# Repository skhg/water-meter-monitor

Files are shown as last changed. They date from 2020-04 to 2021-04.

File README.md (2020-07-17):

# water-meter-monitor
This is a project to measure my household water consumption in real-time using Arduino. The project also evolved a little bit to record the bathroom environment (temperature, humidity, etc).

This repo covers only the design and construction of the monitor. To record data, the [data logger](https://github.com/skhg/household-data-logger) project also needs to be run on the same LAN.

## The finished product
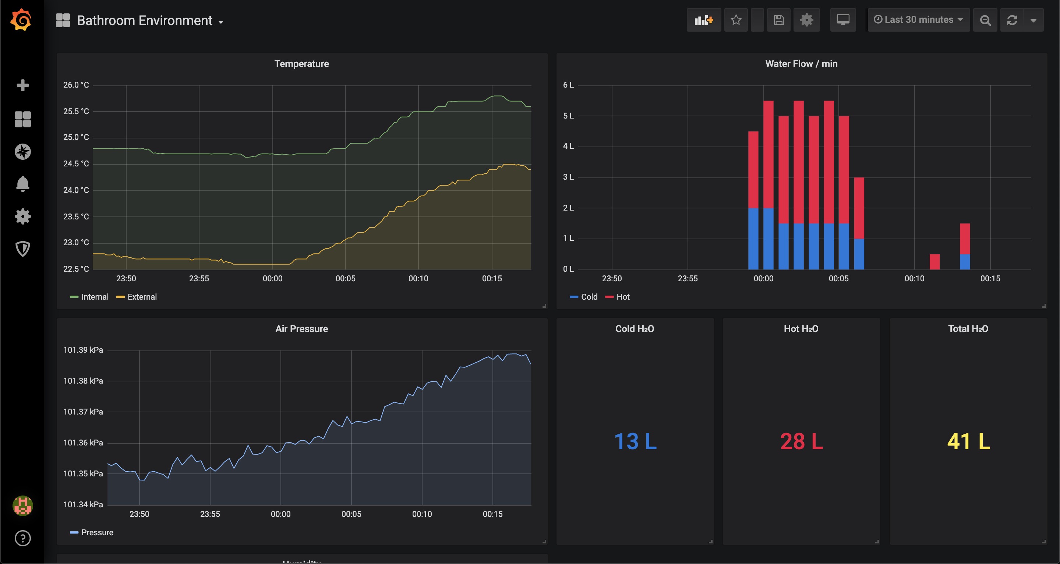
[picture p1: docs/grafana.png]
dashboard

A dashboard set up to display the data using [Grafana](https://grafana.com/). Again, see the [data logger](https://github.com/skhg/household-data-logger) project for how this is set up.

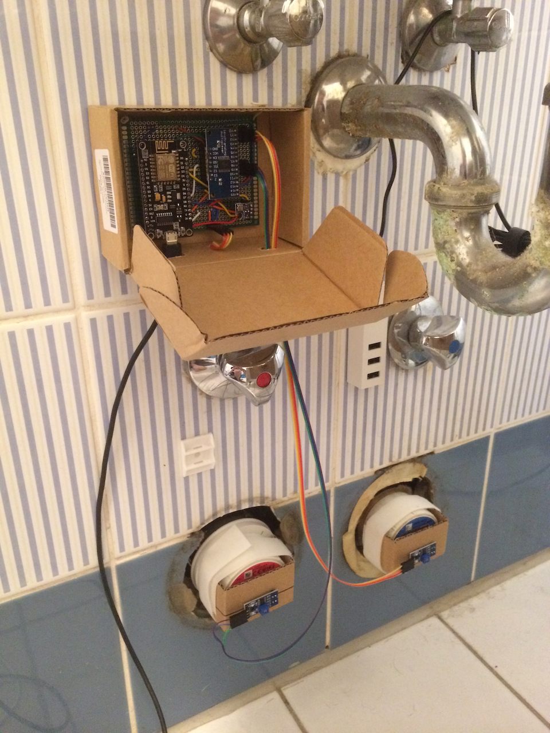
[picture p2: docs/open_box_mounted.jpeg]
installed hardware

The installed sensors and Arduino board. Please excuse the dirt and corroded pipes.

## Materials needed
* Hot/cold water meters with that spinning silver disc
* Arduino-compatible [NodeMCU ESP8266](https://www.amazon.de/dp/B06Y1ZPNMS/ref=pd_bap_rp_29?_encoding=UTF8&psc=1&refRID=00VJ4MZWJ40VXXT9V9F5) board.
* [BMP180 temperature/air pressure sensor](https://www.amazon.de/dp/B07D8S617X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)
* [DHT22 temperature/humidity sensor](https://www.amazon.de/dp/B06XF4TNT9/ref=pd_bap_rp_33?_encoding=UTF8&psc=1&refRID=00VJ4MZWJ40VXXT9V9F5)
* 2x [TCRT5000 Infrared reflectivity sensor](https://www.amazon.de/dp/B017CWS47E/ref=pd_bap_rp_35?_encoding=UTF8&psc=1&refRID=00VJ4MZWJ40VXXT9V9F5)
* [Multiplexer board](https://www.amazon.de/dp/B06Y1L95GK/ref=pd_bap_rp_42?_encoding=UTF8&psc=1&refRID=XGM1T4VMY7AQ8G2ZQ25K)
* A cardboard box
* Some ribbon cables

## Design
The constraints here were that the box needed to be a little distant from the meters themselves. When someone comes along to read the meters in real life, I wanted to be able to easily disconnect things and keep everything tidy. I also wanted the humidity sensor to be on the outside, so it would respond to the ambient air quickly. The air pressure sensor could be on the inside. Conveniently the BMP180 also includes a temperature sensor, so I can get internal/external temperature difference. (Internal temperature is usually about 2°C higher).

The reflectance sensors have digital or analog output, and for this project I needed to use the analog data, so I could get a range of values, rather than a strict "on/off" value. The NodeMCU board only supports a single analog input pin, which meant I had to use the multiplexer to read the two reflectance sensors in turn.

The basic circuit diagram:
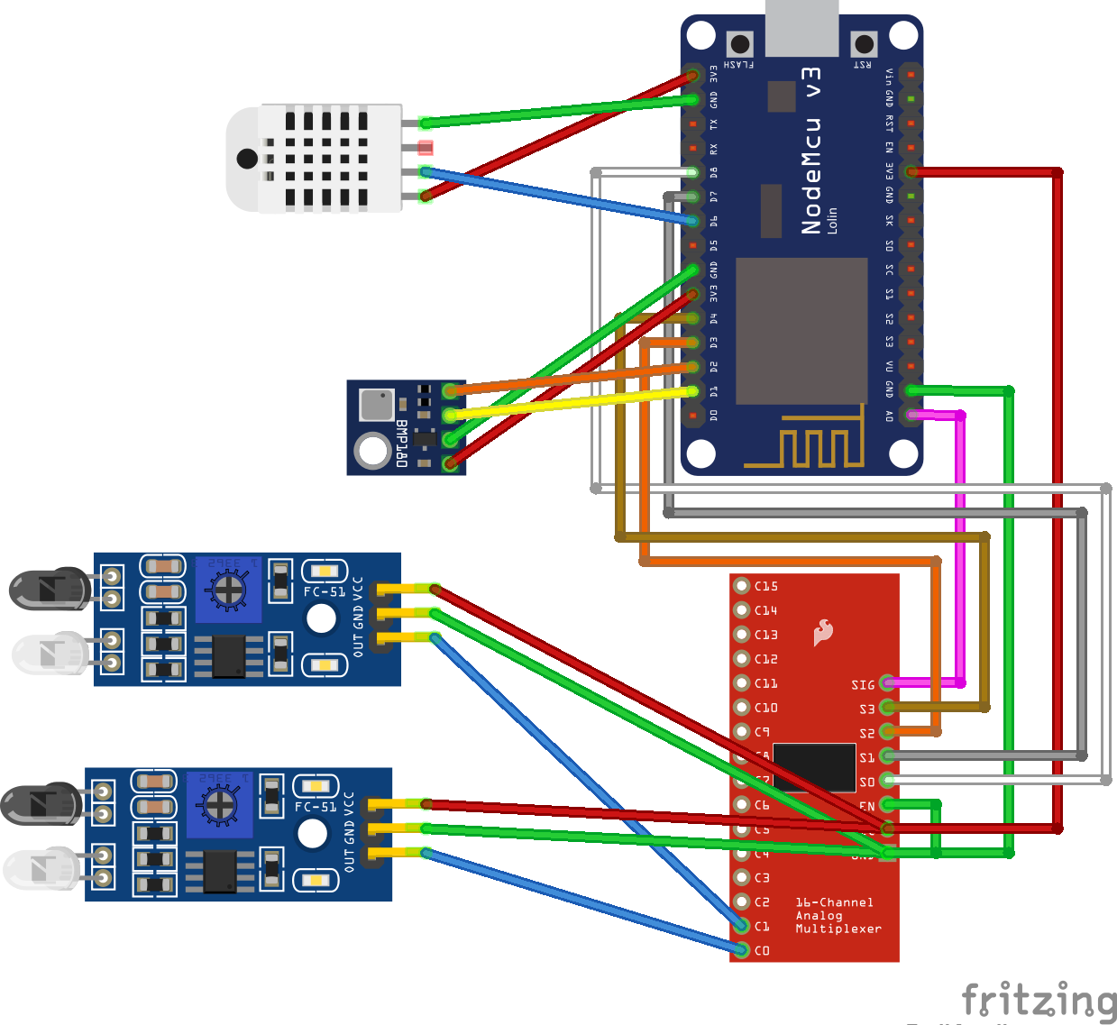
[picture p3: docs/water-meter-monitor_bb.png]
basic diagram


And the circuit layout on the board:
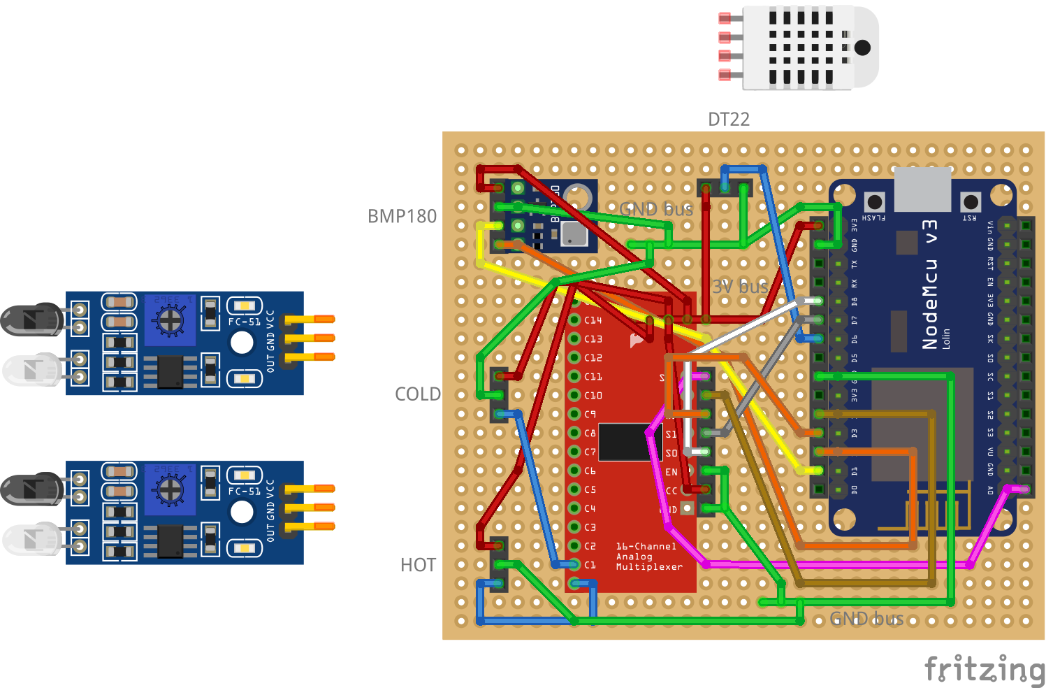
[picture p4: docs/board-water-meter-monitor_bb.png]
board diagram


## Construction
I prototyped the circuit on a breadboard:
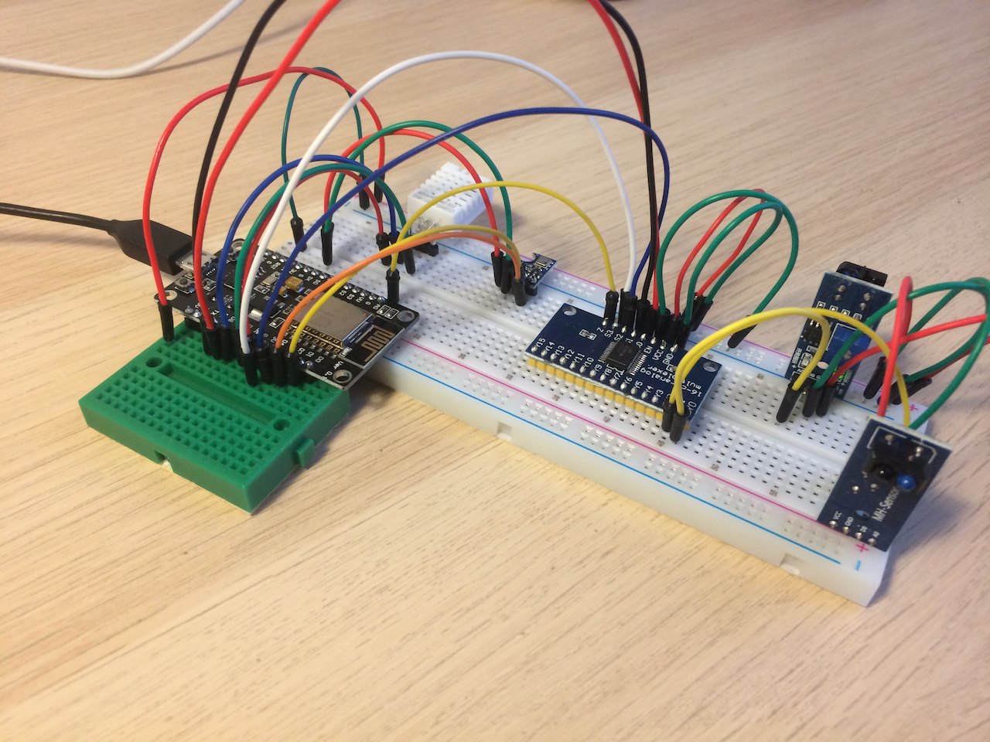
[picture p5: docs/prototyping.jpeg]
breadboard


And installed it in this nice little box, with some slots cut out to pass through the ribbon cables for data, and the USB power cable. The humidity sensor is mounted on the outside:
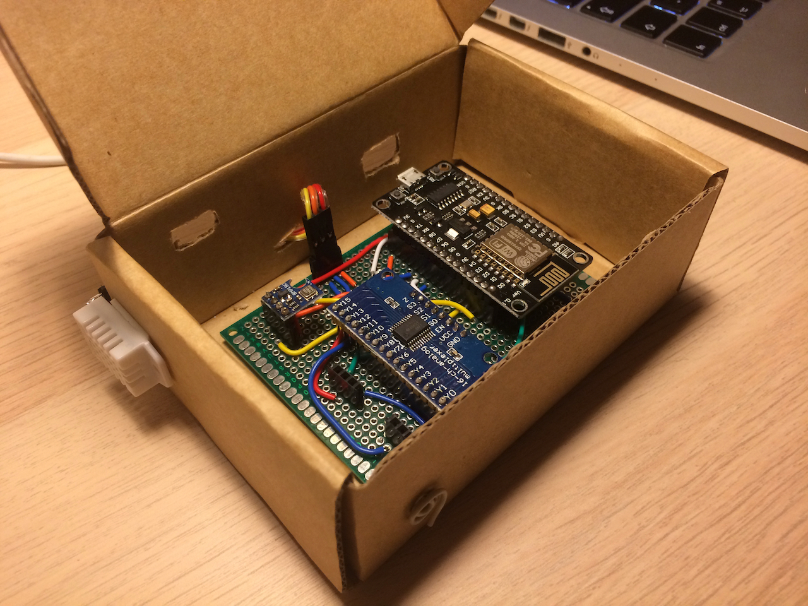
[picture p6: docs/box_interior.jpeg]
box interior


The sensors were "mounted" onto the water meters using a seriously reliable setup of cardboard and velcro, with a slot cut through the cardboard to admit the infrared emitter/recievers:
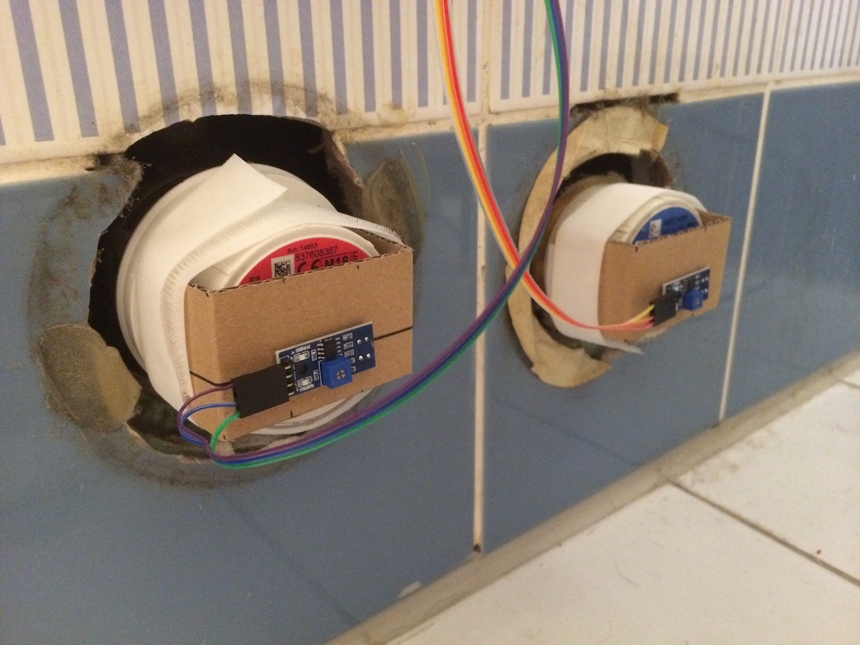
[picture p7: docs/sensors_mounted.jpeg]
sensors mounted


And finally everything is plugged in and switched on. The sensors permanently show a lit green LED when power flows:
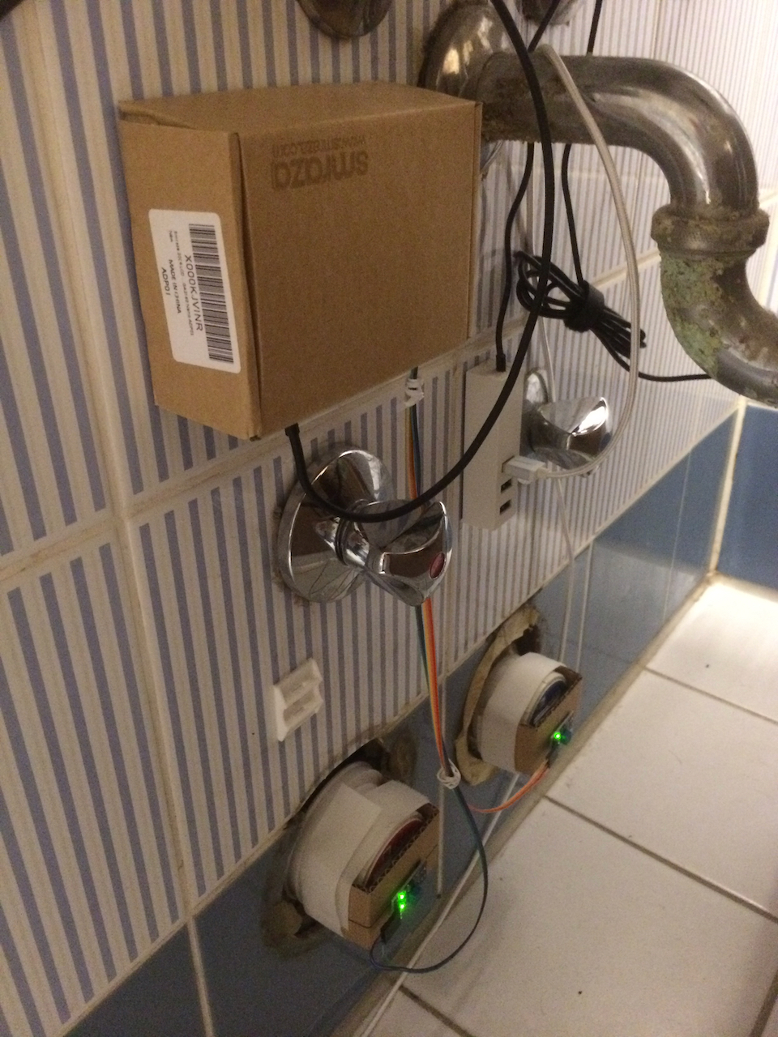
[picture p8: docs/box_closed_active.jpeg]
all turned on


## Software design
As you can see in the [testing](testing/) directory, I tested the various sensors and components independently before integrating them in the [final application](water-meter-monitor.ino).

Some general configuration options are set at the top of the `.ino` file. A little further down the IP and port are specified, where the results will be sent to. Note: If nothing is listening at the far end, the application will crash and attempt to retry forever.

The job of the reflectance sensor is to try to sense whether the spinning disc has moved since the last reading. The sensor should ideally be positioned a bit further to the outside of the disc's radius, if possible. As the disc turns, the sensor's reading will rise and fall.

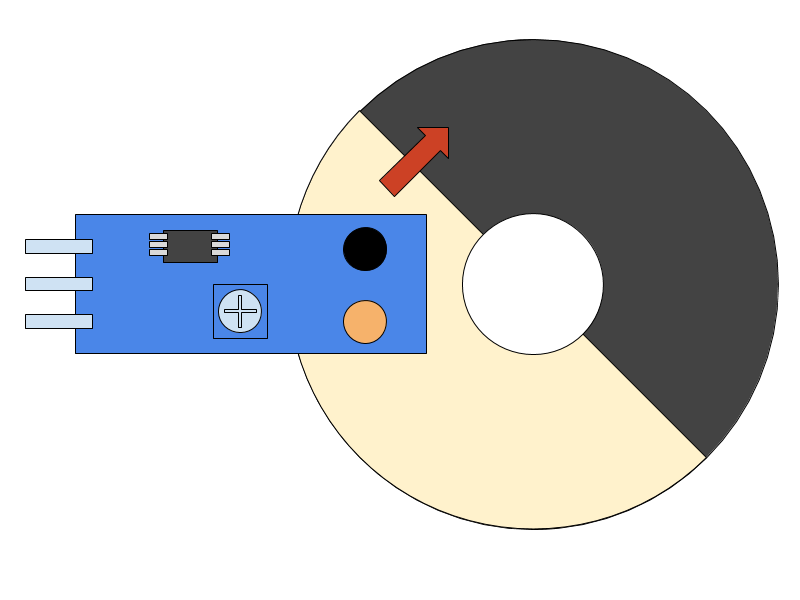
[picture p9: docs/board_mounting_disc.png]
sensor diagram


The reflectivity will always follow a repeating curve, e.g. as can be seen in the following graph:

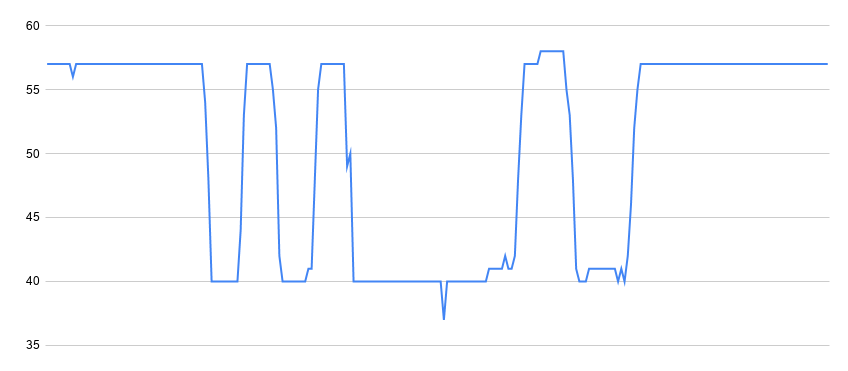
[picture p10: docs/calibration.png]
calibration curve


During constant rotation the level will stay mostly "high" or "low" and rapidly switch between these two. However when water flow stops, it might come to a rest "half way" along the cliff. So the software needs to define two threshold values which need to be crossed, before "high" can become "low" and vice versa.

We must also deal with the case where the device reboots. This could happen due to a WiFi dropout, inability to connect to the server, or a simple power outage. Each time our recorded state changes, we write the new value to the onboard `EEPROM` memory. When we restart, this is read back and is used to continue from where we left off. Without this, reboots frequently cause invalid readings, as we go from a "null" state into a "high" or "low" state.

In `setup()` I define some memory locations where the current state of the sensors is recorded. There is also a short startup delay `STARTUP_DELAY_MS` so that the BMP180 sensor can come online. Trying to read it before its initialization is complete causes unrecoverable errors. The rest of `setup()` is mostly concerned with defining pin locations and voltages. 

In the `loop()` we take our readings, build some JSON, and fire it off to the logging server. If this works, we sleep a little bit, and then repeat. If we fail to connect for any reason, we reboot. This is a quick and easy way of avoiding WiFi reconnection which I found very problematic.

The `*_moved()` methods switch the multiplexer to read from one or other of the sensors. They then use `takeReading(...)` to get the analog reflectivity value and return it. If `CALIBRATION` is enabled they will also print the recorded value, to assist in the setup process.

The JSON sent to the server looks like:

```json
{
  "waterFlow": {
    "hotLitres": 0.5,
    "coldLitres": 0.5
  },
  "environment": {
    "humidityPercentage": 54.0,
    "airPressurePa": 102650,
    "temperatureInternalC": 25.03,
    "temperatureExternalC": 23.3
  }
}
```

## Calibration
The sensors need to be securely attached before calibration begins because even the slightest movement later on will mess it up. With the Arduino "Serial Monitor" window open, run some water and watch the values change. After a few spins of the wheel a repeating pattern will emerge, like in the graph above.

I took the values 20% below the peak and 20% above the trough, as my trigger thresholds. These will be different for any different meters you read because the combination of the sensor and the meter itself is unpredictable. These values need to be set in code and uploaded again to the Arduino board.

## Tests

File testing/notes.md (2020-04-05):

http://henrysbench.capnfatz.com/henrys-bench/arduino-projects-tips-and-more/arduino-ide-nodemcu-esp-12e-digital-input-basics/
http://patriot-geek.blogspot.com/2017/03/nodemcu-and-digital-sensors.html

IR sensor
https://www.instructables.com/id/How-to-Use-TCRT5000-IR-Sensor-Module-With-Arduino-/

Pinout
https://www.instructables.com/id/Getting-Started-With-ESP8266LiLon-NodeMCU-V3Flashi/

combine multiple sensors
http://techiesms.com/iot-projects/controlling-multiple-appliances-using-google-assistant-monitoring-multiple-sensors-data-via-internet/

multiplexer
http://bildr.org/2011/02/cd74hc4067-arduino/

pinout map
https://www.theengineeringprojects.com/2018/10/introduction-to-nodemcu-v3.html

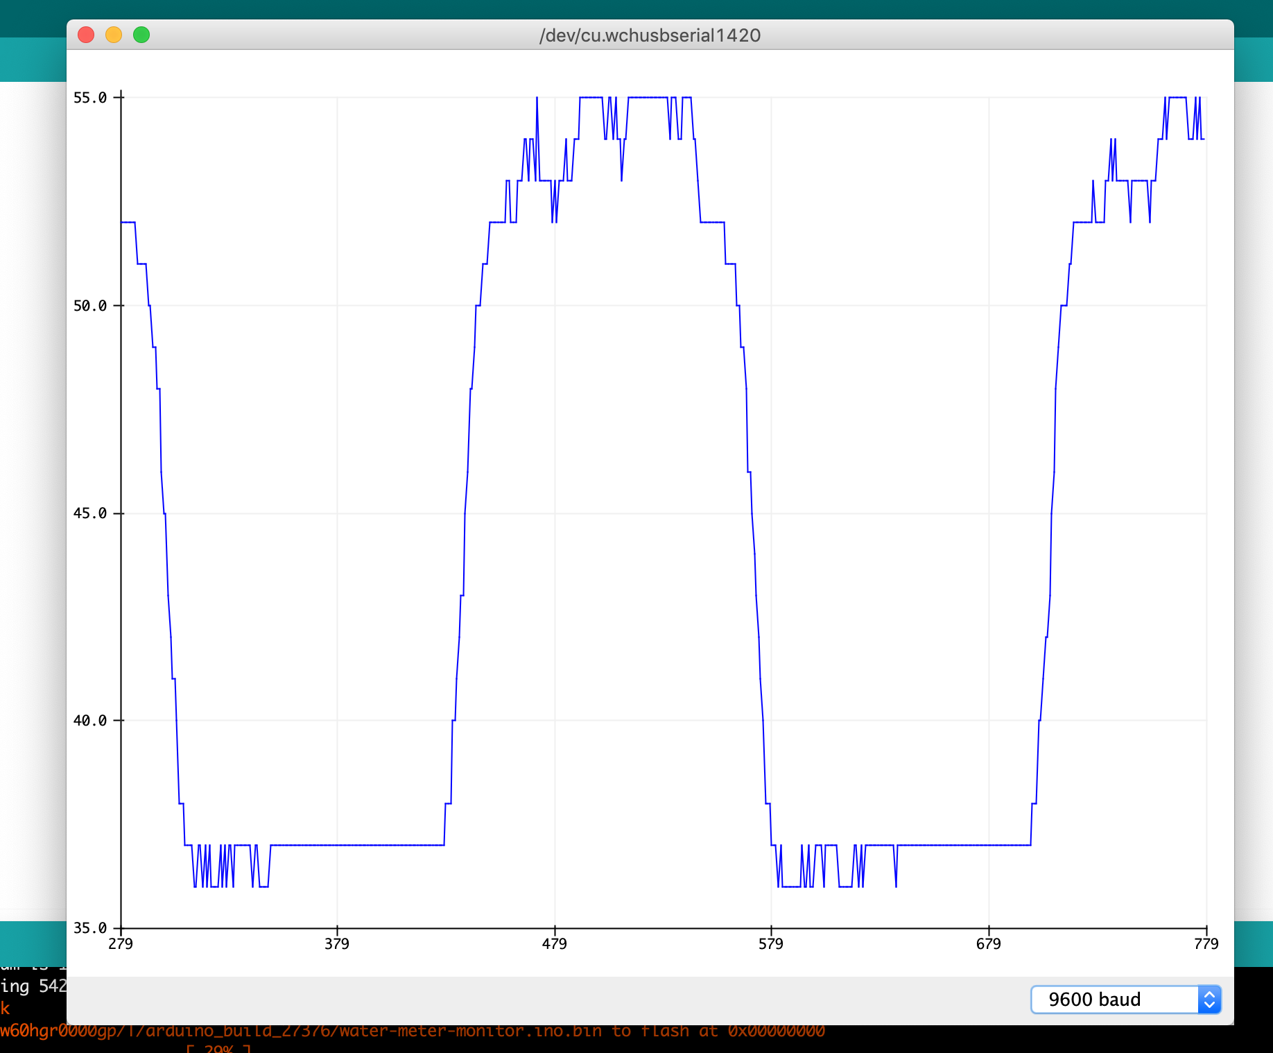
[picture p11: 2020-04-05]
testing/hot_meter.png

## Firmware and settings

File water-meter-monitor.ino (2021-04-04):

/**
 * Copyright 2020 Jack Higgins : https://github.com/skhg
 * All components of this project are licensed under the MIT License.
 * See the LICENSE file for details.
 */

/**
 * Water meter monitor application.
 */

/**
 * Program operates in 3 modes:
 * MONITORING - record data from sensors and send it over REST to a logging server
 * CALIBRATION - prints values to the serial console, to help setting the threshold values
 * PLOTTER - prints values to the serial console, to visualise the reflectance values and aid in debugging
 */
#define ACTIVE_RUN_MODE MONITORING

/**
 * Cold water sensor - reflectance threshold values. Estimated from CALIBRATION mode
 */
#define COLD_ACTIVE true
#define COLD_THRESHOLD_HIGH 980
#define COLD_THRESHOLD_LOW 864

/**
 * Hot water sensor - reflectance threshold values. Estimated from CALIBRATION mode
 */
#define HOT_ACTIVE true
#define HOT_THRESHOLD_HIGH 52
#define HOT_THRESHOLD_LOW 43

/**
 * When no water is flowing, how often do we report the "weather conditions" in the bathroom
 */
#define REPORT_INTERVAL_SECONDS 300

/**
 * Quantity of water represented by one-half rotation of the meter's wheel
 */
#define FLOW_DETECTION_LITRES 0.5

/**
 * IP Address and port to send data to
 */
#define SERVER_ADDRESS "http://192.168.178.29:8080"
#define URL_PATH "/data/live"

/**
 * Network hostname for the system
 */

const String HOSTNAME = "bathroom";










/**
 * System configuration values.
 * 
 * These are unlikely to be needed to be changed after development is complete
 */

/**
 * Short wait on startup to try to prevent the BMP180 sensor for returning bad data
 */
#define STARTUP_DELAY_MS 5000

/*
  NodeMCU v3 Arduino/Physical pinout map
  
  Arduino | NodeMCU | Available for use
  0       | D3      | M_S2
  1       | TX      | X
  2       | D4      | M_S3
  3       | RX      | X
  4       | D2      | BMP180
  5       | D1      | BMP180
  6       |         | X
  7       |         | X
  8       |         | X
  9       | S2      | X
  10      | S3      | X
  11      |         | X
  12      | D6      | DHT22
  13      | D7      | M_S0
  14      | D5      | ?
  15      | D8      | M_S1
  16      | D0      | ?
 */
#define PIN_ANALOG_IN A0
#define PIN_MULTIPLEXER_S0 13
#define PIN_MULTIPLEXER_S1 15
#define PIN_MULTIPLEXER_S2 0
#define PIN_MULTIPLEXER_S3 2
#define PIN_DHT_SENSOR 12
#define DHT_SENSOR_TYPE DHT22

#include <ESP8266WiFi.h>
#include <ESP8266HTTPClient.h>
#include <home_wifi.h>
#include <DHT.h>
#include <Wire.h>
#include <Adafruit_BMP085.h>
#include <EEPROM.h>
#include <ArduinoJson.h>

/**
 * String default values
 */
#define EMPTY_STRING ""
#define HTTP_CONTENT_TYPE_HEADER "Content-Type"
#define HTTP_CONTENT_LENGTH_HEADER "Content-Length"
#define HTTP_JSON_CONTENT_TYPE "application/json"

/**
 * Configuration for saving sensor states to NVRAM
 */

#define COLD_STATE_LOC 0
#define HOT_STATE_LOC 1

/**
 * Application starts here
 */
DHT _dht(PIN_DHT_SENSOR, DHT_SENSOR_TYPE);
Adafruit_BMP085 _bmp;
WiFiClient WIFI_CLIENT;
HTTPClient HTTP_CLIENT;

enum RUN_MODES {
  CALIBRATION,
  PLOTTER,
  MONITORING
};

enum METER_STATE {
  REFLECT_HIGH,
  REFLECT_LOW
};

METER_STATE _coldState;
METER_STATE _hotState;

int _calibrationColdMin = 1024;
int _calibrationHotMin = 1024;
int _calibrationColdMax = 0;
int _calibrationHotMax = 0;

uint64_t _lastReportMillis = 0;

double _hotLitres = 0.0;
double _coldLitres = 0.0;

void setup() {
  Serial.begin(115200);

  Serial.println(EMPTY_STRING);
  Serial.println("Booting...");

  delay(STARTUP_DELAY_MS);

  if (ACTIVE_RUN_MODE == MONITORING) {
    connectToWifi();
    readSavedState(&_coldState, &_hotState);

    Serial.println("Starting sensors...");

    _dht.begin();
    _bmp.begin();
  }

  Serial.println("Configuring pins...");

  pinMode(PIN_ANALOG_IN, INPUT);

  pinMode(PIN_MULTIPLEXER_S0, OUTPUT);
  pinMode(PIN_MULTIPLEXER_S1, OUTPUT);
  pinMode(PIN_MULTIPLEXER_S2, OUTPUT);
  pinMode(PIN_MULTIPLEXER_S3, OUTPUT);

  digitalWrite(PIN_MULTIPLEXER_S0, LOW);
  digitalWrite(PIN_MULTIPLEXER_S1, LOW);
  digitalWrite(PIN_MULTIPLEXER_S2, LOW);
  digitalWrite(PIN_MULTIPLEXER_S3, LOW);

  if (ACTIVE_RUN_MODE == PLOTTER) {
    Serial.println("Cold, Hot");
  }
}

void loop() {
  bool coldFlow = COLD_ACTIVE && coldWaterFlow();
  bool hotFlow = HOT_ACTIVE && hotWaterFlow();

  switch (ACTIVE_RUN_MODE) {
    case PLOTTER: plotter(); break;
    case CALIBRATION: calibrator(); break;
    case MONITORING: monitoring(hotFlow, coldFlow); break;
  }
}

/**
 * Prints a single line of CSV values to be used with the Arduino IDE plotter mode
 */
void plotter() {
  Serial.println(EMPTY_STRING);
  delay(250);
}

/**
 * Print the calibration helper details
 */
void calibrator() {
  calibrationHelper();
  Serial.println("---");
  delay(250);
}

/**
 * Run the continuous monitoring mode. This reads from the two water meters,
 * and stores their state in case of power failure. It then reads from the other onboard
 * sensors.
 * 
 * If we have reached the interval where we must submit readings, or if water flow has
 * been detected, we submit data to the server. Otherwise we skip out.
 */
void monitoring(bool hotFlow, bool coldFlow) {
  if (hotFlow) {
    Serial.print("Hot meter is now ");
    Serial.println(meterStateToString(_hotState));

    EEPROM.write(HOT_STATE_LOC, static_cast<int>(_hotState));

    _hotLitres = _hotLitres + FLOW_DETECTION_LITRES;
  }

  if (coldFlow) {
    Serial.print("Cold meter is now ");
    Serial.println(meterStateToString(_coldState));

    EEPROM.write(COLD_STATE_LOC, static_cast<int>(_coldState));

    _coldLitres = _coldLitres + FLOW_DETECTION_LITRES;
  }

  EEPROM.commit();

  float humidity_percentage = _dht.readHumidity();
  float dht_temperature_c = _dht.readTemperature();
  float bmp_temperature_c = _bmp.readTemperature();
  float pressure_pa = _bmp.readPressure();

  String json = sensorValuesToJsonString(_hotLitres, _coldLitres,
    humidity_percentage, pressure_pa, bmp_temperature_c, dht_temperature_c);

  if (hotFlow || coldFlow || timeForReport(_lastReportMillis)) {
    _lastReportMillis = millis();

    if (sendReadings(json)) {
      // Reset the accumulated litres if we sent them
      _coldLitres = 0.0;
      _hotLitres = 0.0;
    }
  }
}

void readSavedState(METER_STATE*coldState, METER_STATE*hotState) {
  EEPROM.begin(512);

  Serial.println("Loading saved state from NVRAM...");

  int coldStored = EEPROM.read(COLD_STATE_LOC);
  int hotStored = EEPROM.read(HOT_STATE_LOC);

  /** 
   * On first boot with a new board, EEPROM values will be randomised 
   * This resets it to a known safe value
   */
  if (coldStored > 1) {
    coldStored = 0;
    EEPROM.write(COLD_STATE_LOC, 0);
  }

  /**
   * Same as above
   */
  if (hotStored > 1) {
    hotStored = 0;
    EEPROM.write(HOT_STATE_LOC, 0);
  }

  EEPROM.commit();

  *coldState = METER_STATE(coldStored);
  *hotState = METER_STATE(hotStored);

  Serial.println("Saved state:");
  Serial.println("Cold: "+ meterStateToString(*coldState));
  Serial.println("Hot: "+ meterStateToString(*hotState));
}

bool timeForReport(uint64_t lastReportMillis) {
  return (millis() - lastReportMillis) > (REPORT_INTERVAL_SECONDS * 1000);
}

/**
 * A toString helper method for logging the meter's state
 */
String meterStateToString(METER_STATE state) {
  switch (state) {
    case REFLECT_HIGH: return "SHINY";
    case REFLECT_LOW: return "DARK";
    default: return "Unknown";
  }
}

/**
 * Transmit the readings to the logging server
 */
boolean sendReadings(String json) {
  HTTP_CLIENT.begin(WIFI_CLIENT, String(SERVER_ADDRESS) + String(URL_PATH));

  HTTP_CLIENT.addHeader(HTTP_CONTENT_TYPE_HEADER, HTTP_JSON_CONTENT_TYPE);
  HTTP_CLIENT.addHeader(HTTP_CONTENT_LENGTH_HEADER, String(json.length()));
  int result = HTTP_CLIENT.POST(json);

  if (200 <= result && result < 300) {
    Serial.print("Succeeded with response code: ");
    Serial.println(result);
    return true;
  } else {
    Serial.print("Failed with response code: ");
    Serial.println(result);
    return false;
  }
}

/**
 * Convert the full set of readings to a JSON blob
 */
String sensorValuesToJsonString(double hotLitres, double coldLitres,
  float humidityPercentage, float pressurePa, float internalTemp,
  float externalTemp) {
  String content;

  const size_t capacity = 2*JSON_OBJECT_SIZE(2) + JSON_OBJECT_SIZE(4);
  DynamicJsonDocument doc(capacity);

  JsonObject waterFlow = doc.createNestedObject("waterFlow");
  waterFlow["hotLitres"] = hotLitres;
  waterFlow["coldLitres"] = coldLitres;

  JsonObject environment = doc.createNestedObject("environment");
  environment["humidityPercentage"] = humidityPercentage;
  environment["airPressurePa"] = pressurePa;
  environment["temperatureInternalC"] = internalTemp;
  environment["temperatureExternalC"] = externalTemp;

  serializeJson(doc, content);

  return content;
}

/**
 * When running in CALIBRATION mode, this method estimates the thresholds we should
 * use, based on a floor of 20% inside the maximum/minimum recorded values
 */
void calibrationHelper() {
  Serial.println("Cold: Range " + String(_calibrationColdMin) + " to " +
  String(_calibrationColdMax));
  Serial.println("Hot: Range " + String(_calibrationHotMin) + " to " +
  String(_calibrationHotMax));

  int lowTrigger;
  int highTrigger;
  Serial.println("Recommended trigger levels (20% above and below max/min)");

  calculateThresholds(_calibrationColdMin, _calibrationColdMax, &lowTrigger,
    &highTrigger);
  Serial.println("Cold: Low: " + String(lowTrigger) + " to High " +
    String(highTrigger));

  calculateThresholds(_calibrationHotMin, _calibrationHotMax, &lowTrigger,
    &highTrigger);
  Serial.println("Hot: Low: " + String(lowTrigger) + " to High " +
    String(highTrigger));
}

void calculateThresholds(int low, int high, int*lowTrigger, int*highTrigger) {
  int range = high - low;

  int rangeBuffer = range * 0.2;
  *lowTrigger = low + rangeBuffer;
  *highTrigger = high - rangeBuffer;
}

void connectToWifi() {
  Serial.println("Connecting to WiFi...");

  WiFi.begin(WIFI_SSID, WIFI_PASSWORD);
  WiFi.hostname(HOSTNAME);

  while (WiFi.status() != WL_CONNECTED) {
    delay(500);
    Serial.print(".");
  }

  Serial.println(EMPTY_STRING);
  Serial.print("Connected to ");
  Serial.print(WIFI_SSID);
  Serial.print(" with IP address ");
  Serial.println(WiFi.localIP());
}

bool coldWaterFlow() {
  digitalWrite(PIN_MULTIPLEXER_S0, LOW);
  digitalWrite(PIN_MULTIPLEXER_S1, LOW);

  return meterMoved(&_coldState, COLD_THRESHOLD_HIGH, COLD_THRESHOLD_LOW,
    &_calibrationColdMin, &_calibrationColdMax);
}

bool hotWaterFlow() {
  digitalWrite(PIN_MULTIPLEXER_S0, LOW);
  digitalWrite(PIN_MULTIPLEXER_S1, HIGH);

  return meterMoved(&_hotState, HOT_THRESHOLD_HIGH, HOT_THRESHOLD_LOW,
    &_calibrationHotMin, &_calibrationHotMax);
}

/**
 * Detect if one of the meters moved, which state it's now in, and record logging data
 * for calibration purposes
 */
bool meterMoved(METER_STATE*meterState, int highThreshold, int lowThreshold,
  int*calibrationMin, int*calibrationMax) {
  int readingValue;
  METER_STATE previousState = *meterState;
  *meterState = readMeterState(previousState, highThreshold, lowThreshold,
    &readingValue);

  if (ACTIVE_RUN_MODE == CALIBRATION) {
    *calibrationMin = min(*calibrationMin, readingValue);
    *calibrationMax = max(*calibrationMax, readingValue);
  }

  if (ACTIVE_RUN_MODE == PLOTTER) {
    Serial.print(readingValue);
    Serial.print(",");
  }

  return *meterState != previousState;
}

/**
 * Detect if the meter is showing the SHINY or DARK side
 */
METER_STATE readMeterState(METER_STATE currentState, int highThreshold,
  int lowThreshold, int*reading) {
  *reading = analogRead(PIN_ANALOG_IN);

  if (currentState == REFLECT_HIGH && *reading < lowThreshold) {
    return REFLECT_LOW;
  } else if (currentState == REFLECT_LOW && *reading >  highThreshold) {
    return REFLECT_HIGH;
  }

  return currentState;
}

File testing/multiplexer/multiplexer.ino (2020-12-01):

/**
 * Copyright 2020 Jack Higgins : https://github.com/skhg
 * All components of this project are licensed under the MIT License.
 * See the LICENSE file for details.
 */

int signalPin = A0;

int multiplexer_s0 = 13;
int multiplexer_s1 = 15;
int multiplexer_s2 = 0;
int multiplexer_s3 = 2;


//  Arduino | NodeMCU | Used
//  0       | D3      | M_S2
//  1       | TX      | X
//  2       | D4      | M_S3
//  3       | RX      | X
//  4       | D2      | BMP180
//  5       | D1      | BMP180
//  6       |
//  7       |
//  8       |
//  9       | S2      | X
//  10      | S3      | X
//  11      |
//  12      | D6      | DHT22
//  13      | D7      | M_S0
//  14      | D5      |
//  15      | D8      | M_S1
//  16      | D0      |

void setup() {
  pinMode(signalPin, OUTPUT);
  analogWrite(signalPin, 1024);

  pinMode(multiplexer_s0, OUTPUT);
  pinMode(multiplexer_s1, OUTPUT);
  pinMode(multiplexer_s2, OUTPUT);
  pinMode(multiplexer_s3, OUTPUT);

  multiplexer_one();

  Serial.begin(9600);
}

void loop() {
  delay(1000);
  Serial.println("line");
  multiplexer_one();
  analogWrite(signalPin, 1024);
}

void multiplexer_zero() {
  digitalWrite(multiplexer_s0, LOW);
  digitalWrite(multiplexer_s1, LOW);
  digitalWrite(multiplexer_s2, LOW);
  digitalWrite(multiplexer_s3, LOW);
}

void multiplexer_one() {
  digitalWrite(multiplexer_s0, LOW);
  digitalWrite(multiplexer_s1, HIGH);
  digitalWrite(multiplexer_s2, LOW);
  digitalWrite(multiplexer_s3, LOW);
}

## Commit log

2020-07-17 split the calibration and plotter options, and recalibrate
2020-12-01 Tidy up (#2)
    * ignore file
    * pipeline
    * adafruit required library
    * don't lint wifi - copied code
    * linting
    * linter fixes
    [multiplexer.ino, reflectance_sensors.ino, water-meter-monitor.ino]
